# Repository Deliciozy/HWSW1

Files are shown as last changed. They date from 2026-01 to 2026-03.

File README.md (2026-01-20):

# Heart Rate Change Dial

A wearable bio-sensing system that tracks **changes** in heart rate over time and translates them into a **slow, physical visualization**.  
Instead of showing exact BPM numbers, it computes a simplified **physiological change score** and represents it using a motor-driven dial + LED.

---

## 1) Overview (What it is + general sketch)
**What it does (1–3 sentences):**  
Heart Rate Change Dial uses a wearable pulse sensor to detect heart activity and computes a simplified change score that represents relative changes over time.  
That score is sent wirelessly to a standalone display device, where a motor-driven needle and an LED provide an ambient visualization of change.

**General sketch (highlight physical features):**  
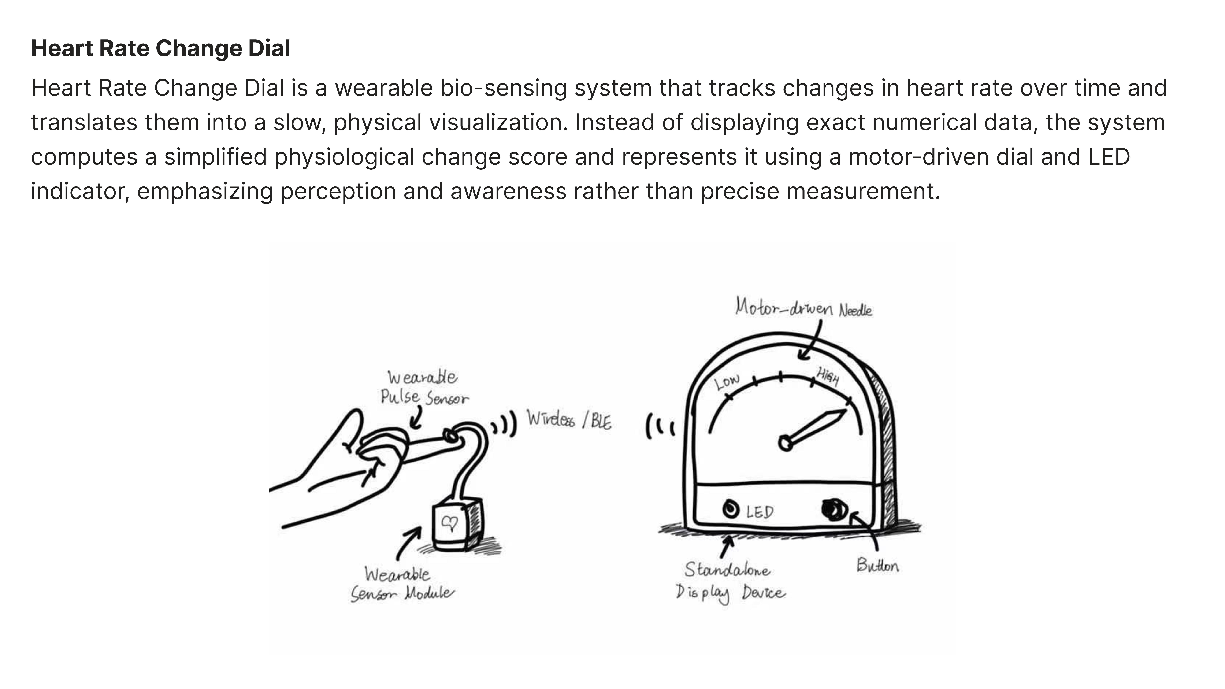
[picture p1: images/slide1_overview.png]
Overview Sketch


---

## 2) Sensor Device (detailed sketch + how it works)
**Device description:**  
The sensor device consists of a wearable pulse sensor connected to an ESP32 microcontroller. It continuously measures heart rate signals, processes short-term variations, and computes a simplified physiological change score representing relative changes in heart activity over time. This processed value is transmitted wirelessly to the display device at a low update rate to reduce noise and power consumption.

**Sensor device sketch:**  
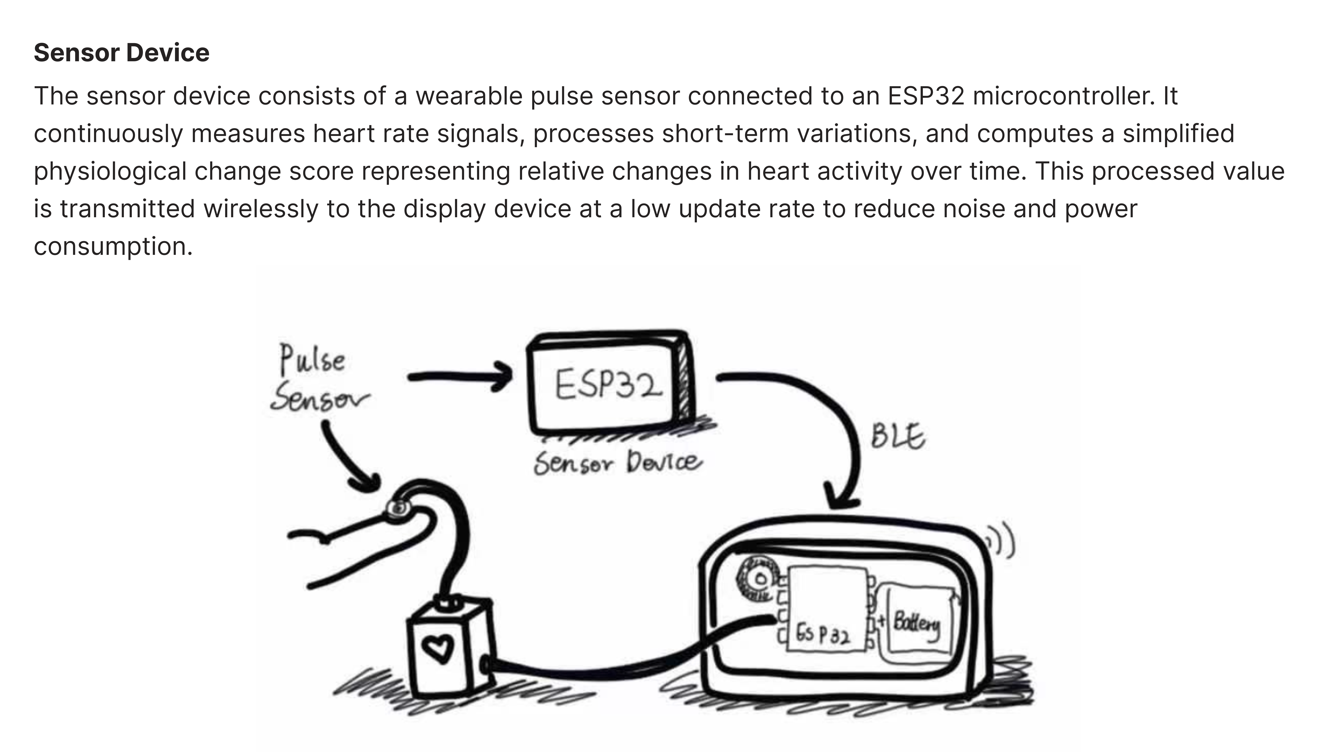
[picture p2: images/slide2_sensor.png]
Sensor Device


---

## 3) Display Device (detailed sketch + how it works)
**Device description:**  
The display device receives physiological change data wirelessly from the sensor device and converts it into a physical representation. A stepper-motor-driven needle slowly moves along a dial to indicate relative heart rate change levels, while an LED provides additional visual feedback. A physical button allows the user to reset or recalibrate the display baseline.

**Display device sketch:**  
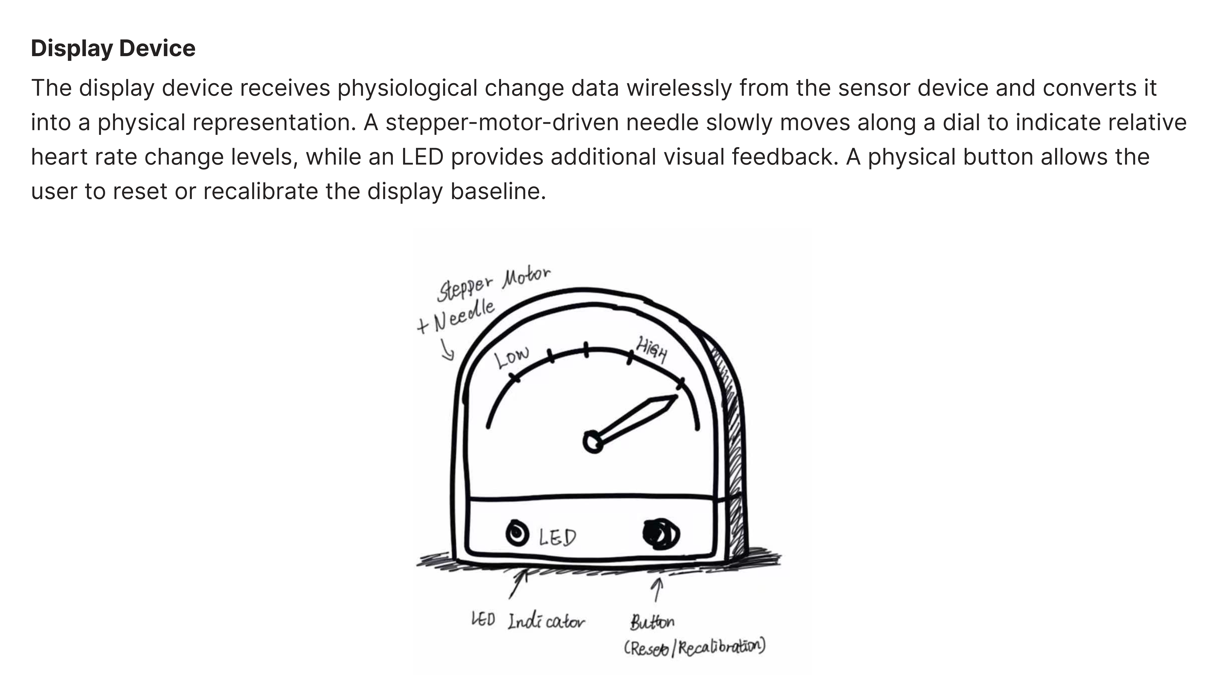
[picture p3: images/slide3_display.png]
Display Device


---

## 4) Diagrams (communication + detailed control/data flow)
This section contains (1) a device communication diagram and (2) a data processing & control flow diagram.

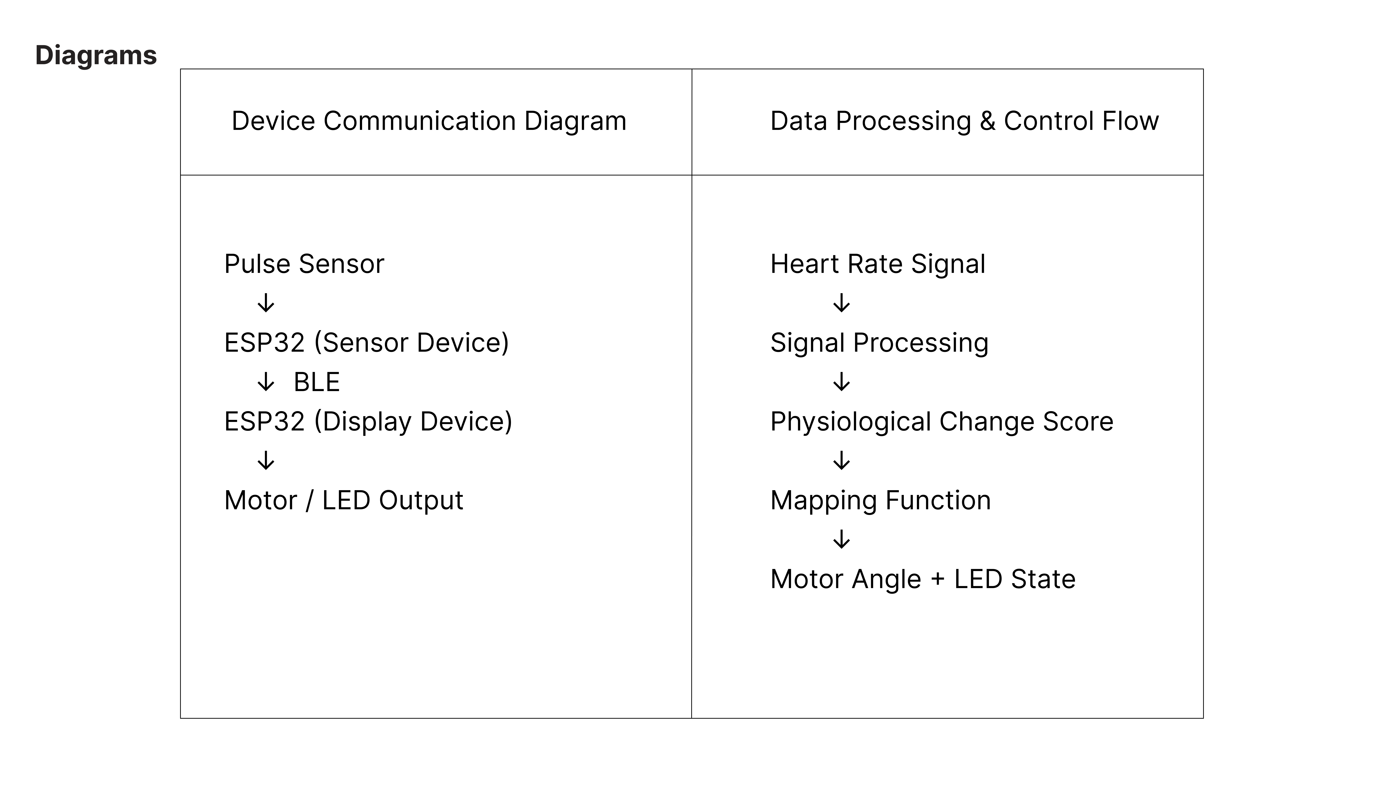
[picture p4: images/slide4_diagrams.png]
Diagrams


---

## Parts List (with part numbers)

### 🔹 Sensor Device (Wearable Sensor Module)

#### Microcontroller
- **Name:** Seeed Studio XIAO ESP32C3  
- **Part Number:** 113991054  
- **Reason:** Ultra-compact ESP32 board with BLE support, suitable for wearable sensing  
- **Datasheet:** `Seeed_XIAO_ESP32C3_Datasheet.pdf`

#### Heart Rate / Pulse Sensor
- **Name:** Pulse Sensor Amped  
- **Part Number:** SEN-11574  
- **Type:** Optical PPG heart rate sensor  
- **Reason:** Designed for Arduino/ESP32 projects, widely used in education and prototyping  
- **Datasheet:** `Pulse_Sensor_Amped_SEN-11574_Datasheet.pdf`

#### Power Source
- **Name:** USB Power / LiPo Battery (3.7V)  
- **Part Number:** N/A (Generic Power Source)  
- **Reason:** Powering the wearable sensor module during prototyping  
- **Datasheet:** `Generic_LiPo_Battery_Datasheet.pdf` 

---

### 🔹 Display Device (Standalone Physical Dial Display)

#### Microcontroller
- **Name:** Seeed Studio XIAO ESP32C3  
- **Part Number:** 113991054  
- **Reason:** Used as a standalone BLE receiver and motor controller  
- **Datasheet:** `Seeed_XIAO_ESP32C3_Datasheet.pdf`  

#### Stepper Motor (Dial Needle)
- **Name:** 28BYJ-48 Stepper Motor (5V)  
- **Part Number:** 28BYJ-48  
- **Reason:** Low-cost stepper motor commonly used for analog dial indicators  
- **Datasheet:** `28BYJ-48_Stepper_Motor_Datasheet.pdf`

#### Stepper Motor Driver
- **Name:** ULN2003 Stepper Motor Driver Board  
- **Part Number:** ULN2003A  
- **Reason:** Required to drive the 28BYJ-48 motor from ESP32 GPIO pins  
- **Datasheet:** `ULN2003A_Datasheet.pdf`

#### LED Indicator
- **Name:** 5mm LED (Red)  
- **Part Number:** Generic 5mm LED  
- **Electrical Specifications:**  
  - Forward Voltage: ~2.0V  
  - Forward Current: 20mA  
- **Datasheet:** `Generic_5mm_LED_Datasheet.pdf`

#### Push Button
- **Name:** Momentary Push Button Switch (Normally Open)  
- **Part Number:** Generic Tactile Switch  
- **Reason:** Used for reset and recalibration interaction  
- **Datasheet:** `Momentary_Push_Button_Datasheet.pdf`

### Sensor device
- Pulse Sensor (PPG heart rate sensor): **Pulse Sensor Amped – SEN-11574** (or your exact model)
- Microcontroller board: **ESP32 board** (put the exact board part number/model you will use, e.g., “Seeed Studio XIAO ESP32C3 – 113991054” if that’s what you have)
- Power: (choose one) LiPo battery model / USB power bank (write the exact battery model if you know it)

### Display device
- Microcontroller board: **ESP32 board** (same as above, list exact model)
- Stepper motor (dial needle): **28BYJ-48 5V stepper motor** (common part name)
- Stepper driver: **ULN2003 driver board**
- LED indicator: **5mm LED** (spec: color, forward voltage, current)  
- Push button: **momentary push button switch** (spec: normally-open)

---

## Datasheets
All datasheets are stored in the `/datasheets` folder as individual PDF files (one PDF per device/part).

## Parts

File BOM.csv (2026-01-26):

Reference | Qty | Value | DNP | Exclude from BOM | Exclude from Board | Footprint | Datasheet
D1 | 1 | LED_RED |  |  |  | LED_SMD:LED_0603 | ~
Pulse_Sensor1 | 1 | Conn_01x03 |  |  |  | Connector_JST:JST_PH_1x03 | ~
R1 | 1 | 330R |  |  |  | Resistor_SMD:R_0603 | ~
Stepper_Motor1 | 1 | 28BYJ-48 Stepper Motor |  |  |  |  | ~
U1,U2 | 2 | ESP32-C3-WROOM-02 |  |  |  | RF_Module:ESP32-C3-WROOM-02 | https://www.espressif.com/sites/default/files/documentation/esp32-c3-wroom-02_datasheet_en.pdf
U3 | 1 | ULN2003 |  |  |  |  | http://www.ti.com/lit/ds/symlink/uln2003a.pdf

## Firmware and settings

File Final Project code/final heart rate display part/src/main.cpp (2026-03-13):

#include <Arduino.h>
#include <Wire.h>
#include <WiFi.h>
#include <esp_now.h>
#include <esp_wifi.h>
#include <stdint.h>

#include <Adafruit_GFX.h>
#include <Adafruit_SSD1306.h>
#include <SwitecX25.h>

// ===== OLED =====
#define SCREEN_WIDTH 128
#define SCREEN_HEIGHT 64
Adafruit_SSD1306 display(SCREEN_WIDTH, SCREEN_HEIGHT, &Wire, -1);

// ===== Hardware =====
const int LED_PIN = D9;
const int BUTTON_PIN = D7;

// ===== Motor (SwitecX25) =====
// 按你刚刚验证能工作的写法
#define MOTOR_STEPS (315 * 3)
SwitecX25 motor1(MOTOR_STEPS, D0, D1, D2, D3);

// ===== ESP-NOW Struct =====
typedef struct __attribute__((packed)) {
  uint32_t seq;
  uint16_t bpm;
  uint8_t finger;
  uint8_t state;   // 0=UNKNOWN, 1=CALM, 2=NEUTRAL, 3=AROUSED
} HeartPacket;

volatile bool newData = false;
HeartPacket incoming = {0, 0, 0, 0};

unsigned long lastPacketTime = 0;
unsigned long lastBlinkTime = 0;
unsigned long lastUiRefresh = 0;
unsigned long lastButtonChangeTime = 0;

bool ledState = false;
bool paused = false;
bool lastButtonReading = HIGH;
bool buttonLatched = false;

// 当前电机目标位置
int motorTarget = MOTOR_STEPS / 2;

// =========================
// Helpers
// =========================
bool linkAlive() {
  return (millis() - lastPacketTime) < 2000;
}

const char* emotionText(uint8_t state, uint8_t finger, bool linked) {
  if (!linked) return "NO LINK";
  if (!finger) return "NO FINGER";

  switch (state) {
    case 1: return "CALM";
    case 2: return "NEUTRAL";
    case 3: return "AROUSED";
    default: return "UNKNOWN";
  }
}

// 用 state 映射到 motor 位置
int getMotorPositionFromState(uint8_t state, uint8_t finger, bool linked, bool pausedNow) {
  if (pausedNow || !linked || !finger) {
    return MOTOR_STEPS / 2;   // 没有信号时回中间
  }

  switch (state) {
    case 1: return MOTOR_STEPS * 1 / 4;   // CALM    左侧
    case 2: return MOTOR_STEPS * 2 / 4;   // NEUTRAL 中间
    case 3: return MOTOR_STEPS * 3 / 4;   // AROUSED 右侧
    default: return MOTOR_STEPS / 2;
  }
}

// 暂停时把线圈拉低
void releaseMotor() {
  pinMode(D0, OUTPUT);
  pinMode(D1, OUTPUT);
  pinMode(D2, OUTPUT);
  pinMode(D3, OUTPUT);

  digitalWrite(D0, LOW);
  digitalWrite(D1, LOW);
  digitalWrite(D2, LOW);
  digitalWrite(D3, LOW);
}

void drawPausedScreen() {
  display.clearDisplay();
  display.setTextColor(WHITE);

  display.setTextSize(1);
  display.setCursor(0, 0);
  display.print("Display");

  display.setTextSize(2);
  display.setCursor(0, 22);
  display.println("PAUSED");

  display.setTextSize(1);
  display.setCursor(0, 52);
  display.println("Press button to resume");

  display.display();
}

void drawScreen() {
  if (paused) {
    drawPausedScreen();
    return;
  }

  display.clearDisplay();
  display.setTextColor(WHITE);

  display.setTextSize(1);
  display.setCursor(0, 0);
  display.print("Display");
  display.setCursor(82, 0);
  display.print("Link: ");
  display.print(linkAlive() ? "OK" : "??");

  display.setTextSize(1);
  display.setCursor(0, 18);
  display.print("Emotion:");

  display.setTextSize(2);
  display.setCursor(0, 30);
  display.println(emotionText(incoming.state, incoming.finger, linkAlive()));

  display.drawFastHLine(0, 54, 128, WHITE);
  display.setTextSize(1);
  display.setCursor(0, 57);
  display.print("BPM:");
  display.print(incoming.bpm);

  display.display();
}

void togglePause() {
  paused = !paused;

  if (paused) {
    digitalWrite(LED_PIN, LOW);
    releaseMotor();
    drawPausedScreen();
  } else {
    // 恢复后重新设目标位置
    motorTarget = getMotorPositionFromState(incoming.state, incoming.finger, linkAlive(), false);
    motor1.setPosition(motorTarget);
    drawScreen();
  }
}

void handleButton() {
  bool reading = digitalRead(BUTTON_PIN);

  if (reading != lastButtonReading) {
    lastButtonChangeTime = millis();
  }

  if ((millis() - lastButtonChangeTime) > 40) {
    if (reading == LOW && !buttonLatched) {
      buttonLatched = true;
      togglePause();
    }

    if (reading == HIGH) {
      buttonLatched = false;
    }
  }

  lastButtonReading = reading;
}

void onReceive(const uint8_t *mac, const uint8_t *data, int len) {
  if (len == sizeof(HeartPacket)) {
    memcpy((void*)&incoming, data, sizeof(HeartPacket));
    lastPacketTime = millis();
    newData = true;
  }
}

// =========================
// Setup
// =========================
void setup() {
  Serial.begin(115200);

  pinMode(LED_PIN, OUTPUT);
  pinMode(BUTTON_PIN, INPUT_PULLUP);

  Wire.begin(D4, D5);

  if (!display.begin(SSD1306_SWITCHCAPVCC, 0x3C)) {
    while (true) {
      delay(10);
    }
  }

  WiFi.mode(WIFI_AP_STA);
  WiFi.softAP("FIND_ME", "12345678", 1);

  if (esp_now_init() == ESP_OK) {
    esp_now_register_recv_cb(onReceive);
  }

  // ===== SwitecX25 init =====
  // 先归零，再回到中间
  motor1.zero();
  motor1.setPosition(MOTOR_STEPS / 2);

  display.clearDisplay();
  display.setTextColor(WHITE);
  display.setTextSize(1);
  display.setCursor(0, 10);
  display.println("Waiting for sensor...");
  display.setCursor(0, 25);
  display.println("MAC:");
  display.println(WiFi.macAddress());
  display.display();
  delay(2000);
}

// =========================
// Loop
// =========================
void loop() {
  unsigned long now = millis();

  handleButton();

  if (paused) {
    digitalWrite(LED_PIN, LOW);
    releaseMotor();
    delay(5);
    return;
  }

  if (now - lastBlinkTime > 500) {
    lastBlinkTime = now;
    ledState = !ledState;
    digitalWrite(LED_PIN, ledState);
  }

  if (newData || (now - lastUiRefresh > 500)) {
    newData = false;
    lastUiRefresh = now;
    drawScreen();
  }

  // 根据收到的 state 更新目标位置
  motorTarget = getMotorPositionFromState(incoming.state, incoming.finger, linkAlive(), paused);
  motor1.setPosition(motorTarget);

  // SwitecX25 必须频繁 update
  motor1.update();

  delay(1);
}

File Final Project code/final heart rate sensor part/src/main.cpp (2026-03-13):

#include <Arduino.h>
#include <WiFi.h>
#include <esp_now.h>
#include <esp_wifi.h>
#include <math.h>

// ===== Hardware =====
const int PULSE_PIN = D0;
const int LED_PIN = D2;

// ===== Target Config =====
const char* TARGET_NAME = "FIND_ME";
uint8_t TARGET_MAC[] = {0x98, 0x3D, 0xAE, 0xAA, 0x71, 0x99};

// ===== Detection Tuning =====
const int FINGER_THRESHOLD = 3000;
const int MARGIN = 130;
const int MIN_BPM = 45;
const int MAX_BPM = 180;
const unsigned long REFRACTORY_MS = 350;

// ===== State =====
bool connected = false;
uint8_t current_target[6];

// ===== Packet =====
typedef struct __attribute__((packed)) {
  uint32_t seq;
  uint16_t bpm;   // processed / smoothed BPM
  uint8_t finger;
  uint8_t state;  // 0=UNKNOWN, 1=CALM, 2=NEUTRAL, 3=AROUSED
} HeartPacket;

HeartPacket packet = {0, 0, 0, 0};

// ===== BPM Variables =====
float baseline = 0;
bool baselineInitialized = false;
bool inBeat = false;
unsigned long lastBeatTime = 0;
int bpmHistory[5] = {0};
int bpmIndex = 0;
int stableBpm = 0;

// ===== Simple Signal Processing =====
float smoothedBpm = 0.0f;
float prevSmoothedBpm = 0.0f;
float bpmDelta = 0.0f;
bool emotionInitialized = false;

// =========================
// AUTO-HUNT LOGIC
// =========================
bool autoHunt() {
  Serial.println("\n[SEARCHING] Looking for " + String(TARGET_NAME) + "...");
  WiFi.mode(WIFI_STA);
  WiFi.disconnect();
  delay(100);

  int n = WiFi.scanNetworks();
  if (n <= 0) return false;

  int nameMatchIdx = -1;
  int nameMatchCount = 0;
  bool macFound = false;

  for (int i = 0; i < n; i++) {
    if (WiFi.SSID(i) == TARGET_NAME) {
      nameMatchIdx = i;
      nameMatchCount++;
    }

    uint8_t* b = WiFi.BSSID(i);
    if (memcmp(b, TARGET_MAC, 6) == 0) {
      macFound = true;
    }
  }

  // 1. If exactly one name match, use it.
  if (nameMatchCount == 1) {
    memcpy(current_target, WiFi.BSSID(nameMatchIdx), 6);
    Serial.println("[MATCH] Found unique " + String(TARGET_NAME));
    return true;
  }

  // 2. Otherwise fallback to specific MAC
  if (macFound) {
    memcpy(current_target, TARGET_MAC, 6);
    Serial.println("[MATCH] Found Target by MAC address.");
    return true;
  }

  return false;
}

void setupESPNOW() {
  if (esp_now_init() != ESP_OK) return;

  esp_now_peer_info_t peerInfo = {};
  memcpy(peerInfo.peer_addr, current_target, 6);
  peerInfo.channel = 0;
  peerInfo.encrypt = false;

  if (esp_now_add_peer(&peerInfo) == ESP_OK) {
    connected = true;
    Serial.println("[OK] ESP-NOW Link Established.");
  }
}

// =========================
// SENSOR LOGIC
// =========================
void processBPM(int raw) {
  unsigned long now = millis();
  bool finger = (raw < FINGER_THRESHOLD);
  packet.finger = finger ? 1 : 0;

  if (!finger) {
    stableBpm = 0;
    baselineInitialized = false;
    inBeat = false;
    lastBeatTime = 0;
    for (int i = 0; i < 5; i++) bpmHistory[i] = 0;
    bpmIndex = 0;
    return;
  }

  if (!baselineInitialized) {
    baseline = raw;
    baselineInitialized = true;
    return;
  }

  baseline = baseline * 0.98f + raw * 0.02f;
  int threshold = (int)baseline + MARGIN;

  if (!inBeat && raw > threshold && (now - lastBeatTime > REFRACTORY_MS)) {
    inBeat = true;

    if (lastBeatTime > 0) {
      int currentBpm = 60000 / (now - lastBeatTime);

      if (currentBpm >= MIN_BPM && currentBpm <= MAX_BPM) {
        bpmHistory[bpmIndex] = currentBpm;
        bpmIndex = (bpmIndex + 1) % 5;

        int sum = 0;
        int count = 0;
        for (int i = 0; i < 5; i++) {
          if (bpmHistory[i] > 0) {
            sum += bpmHistory[i];
            count++;
          }
        }

        if (count > 0) {
          stableBpm = sum / count;
        }
      }
    }

    lastBeatTime = now;
  }

  if (inBeat && raw < baseline) {
    inBeat = false;
  }
}

// =========================
// SIMPLE SIGNAL PROCESSING
// All emotion processing is done here
// =========================
void updateProcessedOutput() {
  // No finger or no valid BPM => clear state
  if (!packet.finger || stableBpm == 0) {
    smoothedBpm = 0;
    prevSmoothedBpm = 0;
    bpmDelta = 0;
    emotionInitialized = false;

    packet.bpm = 0;
    packet.state = 0;  // UNKNOWN
    return;
  }

  // Exponential smoothing parameters
  const float alpha = 0.25f;  // BPM smoothing
  const float beta  = 0.20f;  // delta smoothing

  if (!emotionInitialized) {
    smoothedBpm = stableBpm;
    prevSmoothedBpm = stableBpm;
    bpmDelta = 0;
    emotionInitialized = true;
  } else {
    prevSmoothedBpm = smoothedBpm;
    smoothedBpm = alpha * stableBpm + (1.0f - alpha) * smoothedBpm;

    float d = fabs(smoothedBpm - prevSmoothedBpm);
    bpmDelta = beta * d + (1.0f - beta) * bpmDelta;
  }

  packet.bpm = (uint16_t)(smoothedBpm + 0.5f);

  // Very simple emotion mapping
  if (packet.bpm < 72 && bpmDelta < 1.5f) {
    packet.state = 1;  // CALM
  } else if (packet.bpm > 90 || bpmDelta > 3.0f) {
    packet.state = 3;  // AROUSED
  } else {
    packet.state = 2;  // NEUTRAL
  }
}

// =========================
// MAIN
// =========================
void setup() {
  Serial.begin(115200);
  pinMode(LED_PIN, OUTPUT);
  analogReadResolution(12);

  while (!connected) {
    digitalWrite(LED_PIN, HIGH);
    if (autoHunt()) {
      setupESPNOW();
    } else {
      Serial.println("[RETRY] Target not found. Retrying in 5s...");
      digitalWrite(LED_PIN, LOW);
      delay(5000);
    }
  }

  digitalWrite(LED_PIN, HIGH);
  delay(1000);
  digitalWrite(LED_PIN, LOW);
}

void loop() {
  int raw = analogRead(PULSE_PIN);
  processBPM(raw);
  updateProcessedOutput();

  static unsigned long lastSend = 0;
  if (millis() - lastSend > 800) {
    lastSend = millis();

    packet.seq++;
    esp_now_send(current_target, (uint8_t*)&packet, sizeof(packet));

    Serial.printf("RAW_BPM:%d | OUT_BPM:%d | Finger:%d | State:%d | Delta:%.2f\n",
                  stableBpm, packet.bpm, packet.finger, packet.state, bpmDelta);
  }

  delay(10);
}

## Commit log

2026-01-20 Revise parts list with detailed component information
    Updated the parts list with detailed specifications and datasheets for each component used in the wearable sensor and standalone display devices.
2026-03-01 Add BLE sensor device functionality
